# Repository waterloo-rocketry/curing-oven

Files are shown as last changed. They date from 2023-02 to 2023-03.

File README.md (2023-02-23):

# curing-oven

repository to store all the code and data for the curing oven project

call/text Calvin DeKoter at 650-399-6428 to ask about the project / or give UI tips

TODO 

Things to Fix

	Firmware

		List of issues detailed in powerpoint and also in the code itself
		General performance / best practice things could also be better

	Electrical
		
		There are some layout issues - currently the pressure sensor has been flywired
		A few other flywires and cut traces on the indicator LEDs

		Analog inputs and outputs are untested

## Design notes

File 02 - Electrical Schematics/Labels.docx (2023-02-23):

240 V X 240 V X | 240 V Y 240 V Y | DSW Y DSW Y | DSW X DSW X | AC DC X AC DC X | AC DC Y AC DC Y | OAL X OAL X
OAL Y OAL Y | HTR1 X HTR1 X | HTR1 Y HTR1 Y | BLW1 X BLW1 X | BLW1 Y BLW1 Y | IRO X IRO X | IRO Y IRO Y
SSR1 X SSR1 X | DWYER X DWYER X | F HTR1 X F HTR1 X | F HTR1 Y F HTR1 Y | F BLW1 X F BLW1 X | F BLW1 Y F BLW1 Y | AUX L AUX L
AUX G AUX G | AUX N AUX N | AUX L R AUX L R | IL ESTP IL ESTP | IL TFUSE IL TFUSE | IL DSW IL DSW | 240 V F X 240 V F X
240 V F Y 240 V F Y | AUX L F AUX L F | BUTTONS BUTTONS | DISPLAY DISPLAY | LED1 LED1 | LED2 LED2 | LED3 LED3
240 V X 240 V X | 240 V Y 240 V Y | DSW Y DSW Y | DSW X DSW X | AC DC X AC DC X | AC DC Y AC DC Y | OAL X OAL X
OAL Y OAL Y | HTR1 X HTR1 X | HTR1 Y HTR1 Y | BLW1 X BLW1 X | BLW1 Y BLW1 Y | IRO X IRO X | IRO Y IRO Y
SSR1 X SSR1 X | DWYER X DWYER X | F HTR1 X F HTR1 X | F HTR1 Y F HTR1 Y | F BLW1 X F BLW1 X | F BLW1 Y F BLW1 Y | AUX L AUX L
AUX G AUX G | AUX N AUX N | AUX L R AUX L R | IL ESTP IL ESTP | IL TFUSE IL TFUSE | IL DSW IL DSW | 240 V F X 240 V F X
240 V F Y 240 V F Y | AUX L F AUX L F | BUTTONS BUTTONS | DISPLAY DISPLAY | LED1 LED1 | LED2 LED2 | LED3 LED3

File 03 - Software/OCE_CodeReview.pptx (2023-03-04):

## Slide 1

Oven Code Review
- Code Purpose
  - Accept User Input from buttons
  - Control OCE Outputs, Measure Inputs
  - Manage Errors and Unexpected Inputs

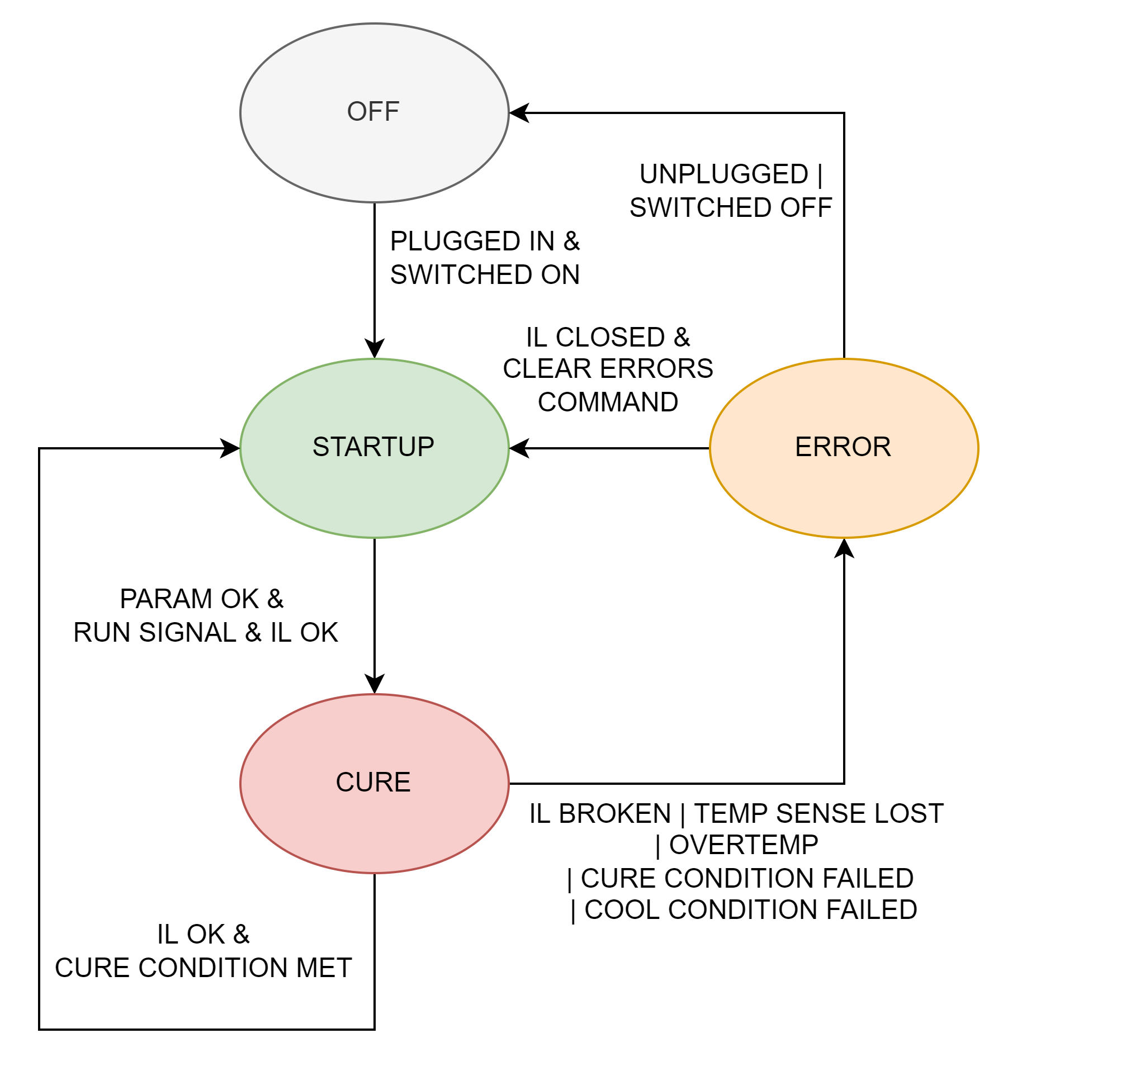
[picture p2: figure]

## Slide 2

List of Issues

Issue Name | Description | Proposed Fix
DataSave Overwrite | DataSave overwrites previous file | Check if the file exists, increment filename if so, display filename on screen
Fix padding | Numbers move around / poorly padded | Add a helper function to display the correct number and in the right position
Control off Screen | C leaves screen on Cure state | Pad number correctly
Therm. 7-9 deselect not working | Interesting | Weird wrapping stuff

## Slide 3

List of Todos

Issue Name | Description | Proposed Fix
Thermistor Screen | Add thermistor screen with all values | Fix scrolling between screens during cure
Real time clock | Add the RTC to the file header | Use the Teensy RTC synced to the PC
Log process T | Log the average temperature | Add a column to the data file
Protect AUX | Protect AUX from on/off cycling | Add a deadtime to the AUX output to avoid repeated starts
EEPROM settings | Oven can save current settings | If the user wishes (control tab), save setup to EEPROM
Ambient Setpoint | Ambient may not match actual | Collect a few seconds of data to set the ambient
OVT / Setpoint Ctrl | Balance setpoint control with OVT | Improve handoff between to targets to prevent oscillation
Menu Issues | Back button goes all the way to the main menu | Fix timing issues (see diagram on startup slide) to properly catch button presses
Thermistor Select | Cursor starts on description text | Adjust offsets so it works better
Cure Menu Display | Add more resolution to time displays | Swap units / padding when t < 1 h, t:tt > 1 h

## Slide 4

Safety Cases to Test

Case | Description | Expected Behaviour | Pass/Fail
Duct Disconnected | Duct is disconnected | No pitot tube, pressure switch wired NC | Fail
Oven Lid Open | Oven partially open | No ability to check without more IL routing | N/A, OoS
High Delta T | Thermistors not consistent | Check disabled to promote oven reliability, no response | Fail
Vacuum Leak | Leak, AUX on for full cure | Allow AUX to run for full cure
PCB Failure | Damage to PCB | Thermal fuse breaks IL after heater runaway | To Check

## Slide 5

Big Questions

Logging file format - .csv
Might be neat to have something with headers

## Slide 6

State 1: Startup

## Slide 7

State 2: Cure

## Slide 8

PID Control

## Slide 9

State 3: Error

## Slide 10

Function Description: driveHTR1()

Function operates on volatile variables to turn the heater output (that switches the SSR) on or off to generate a PWM signal at 60 Hz, duty cycle 0-100%

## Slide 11

Oven Digital Twin

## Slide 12

void setup()

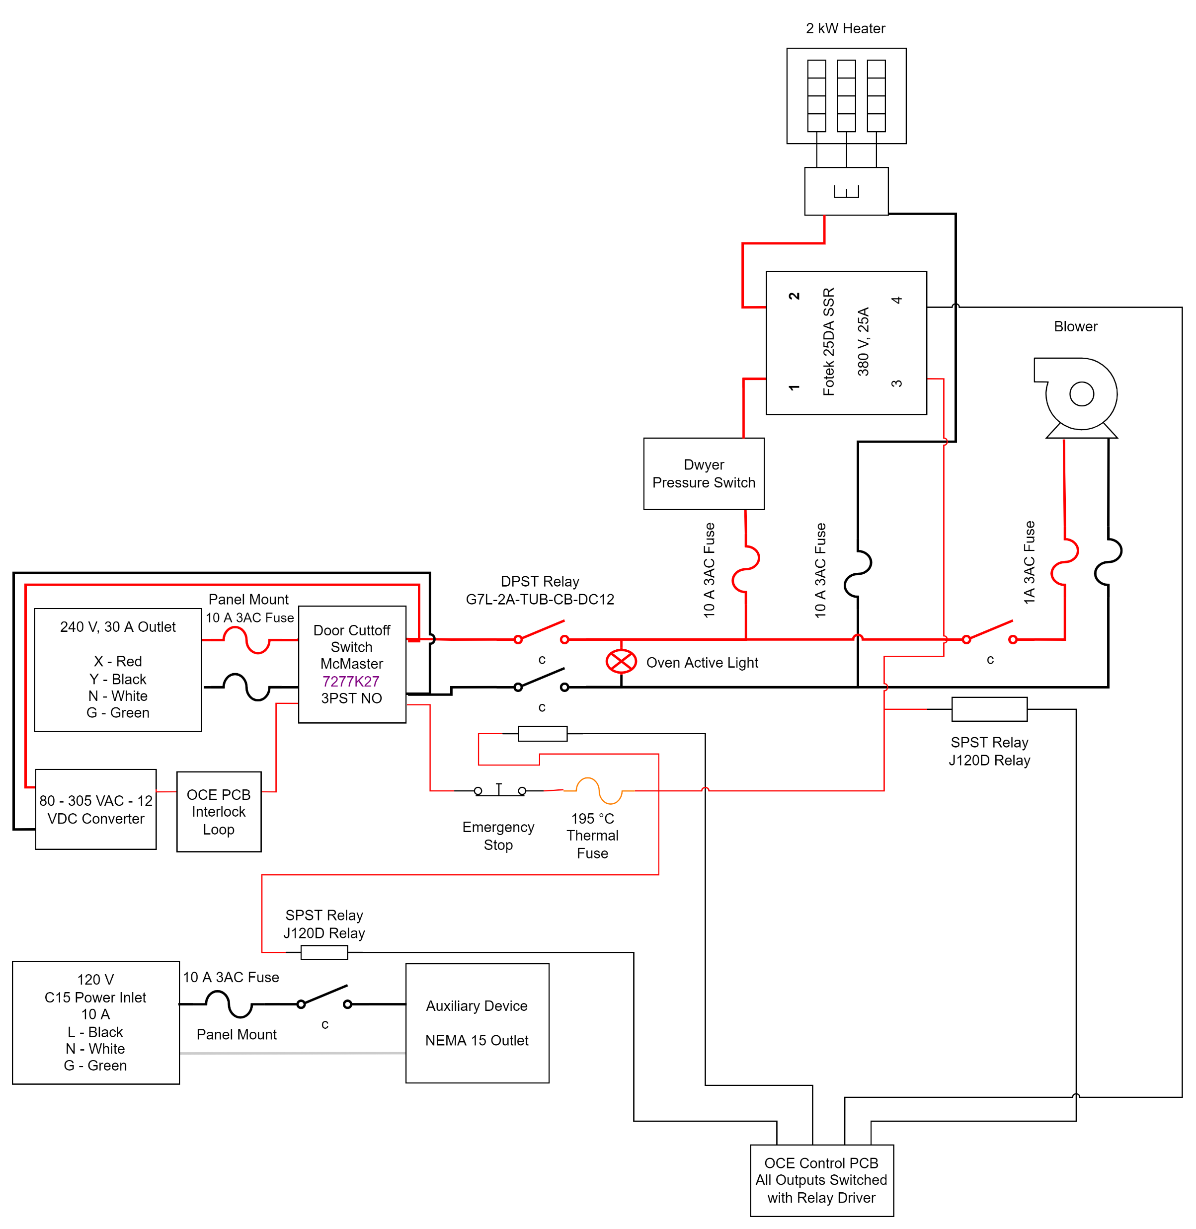
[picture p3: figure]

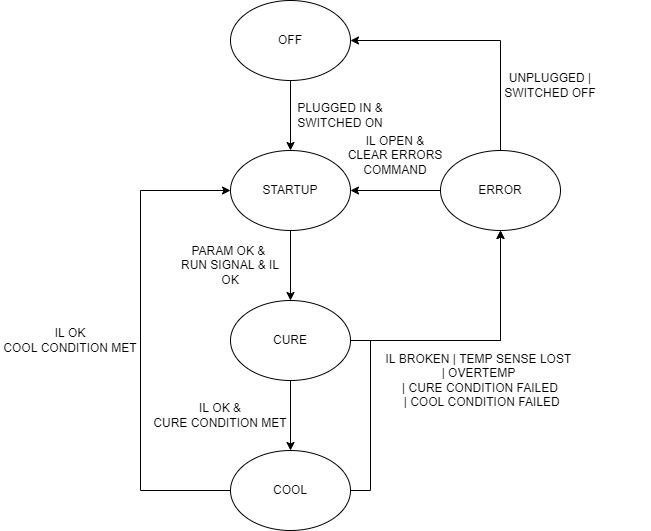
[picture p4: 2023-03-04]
03 - Software/OCE_StateMachine_V2.png

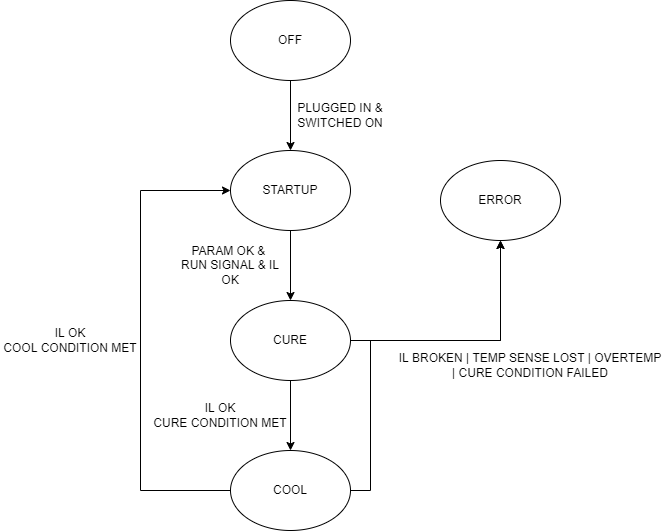
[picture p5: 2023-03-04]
03 - Software/OCE_StateMachine_V1.png

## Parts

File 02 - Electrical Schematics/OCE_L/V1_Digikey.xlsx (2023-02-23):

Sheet: OCE_L (2)
Id | Designator | Package | Quantity | Designation | Supplier and ref | Column1 | _1 | post-PCB
1 | U1 | SOT-223-3_TabPin2 | 1 | AZ1117-3.3 |  |  |  | done
2 | J6 | PinSocket_1x03_P2.54mm_Vertical | 1 | Conn_01x03_Female
3 | U5 | SOT-223-3_TabPin2 | 1 | AZ1117-5.0
4 | U4 | SOIC-16W_7.5x10.3mm_P1.27mm | 1 | MLX90809 |  |  |  | done
5 | J4 | PinSocket_2x12_P2.54mm_Vertical | 1 | Conn_01x24_Female |  |  |  | done
6 | J3 | PinHeader_2x04_P2.54mm_Vertical_Lin | 1 | Conn_02x04_Counter_Clockwise |  |  |  | done
7 | K2,K1 | J120D | 2 | J120D |  |  |  | done
8 | J9 | J1B1211CCD | 1 | J1B1211CCD |  |  |  | done
9 | IC1 | TEENSY41 | 1 | TEENSY_4.1 |  |  |  | done
10 | C3,C4,C5,C6,C16,C22 | C_0805_2012Metric | 6 | 0.1uF
11 | C7,C25,C26 | C_0805_2012Metric | 3 | 100 nF
12 | C9,C11,C12,C13,C14,C15,C17,C18,C19,C20,C21 | C_0805_2012Metric | 11 | 10uF
13 | C10 | C_0805_2012Metric | 1 | 47 nF
14 | J1 | PinSocket_2x03_P2.54mm_Vertical | 1 | Conn_02x03_Counter_Clockwise
15 | J2 | BarrelJack_Horizontal | 1 | Barrel_Jack
16 | R22,R41 | R_0805_2012Metric | 2 | 3.3k
17 | R27,R40 | R_0805_2012Metric | 2 | 4.7k
18 | U2 | SOIC-16_4.55x10.3mm_P1.27mm | 1 | ULQ2004A
19 | U3 | DIP-14_W10.16mm | 1 | LM324
20 | RV1,RV2 | 64WR50KLF | 2 | R_POT
21 | C1,C2 | C_0805_2012Metric | 2 | 10 uF
22 | C23,C24 | C_0805_2012Metric | 2 | 22 uF
23 | R1,R2,R4,R5,R8,R9,R11,R12,R13,R15,R16,R17,R18,R19,R20,R21,R23,R24,R25,R26,R29,R30,R31,R32,R33,R34,R35,R36,R37,R38,R39 | R_0603_1608Metric | 31 | 10k
24 | R7,R10 | R_0603_1608Metric | 2 | 40k
25 | R28 | R_0603_1608Metric | 1 | 10K
26 | J5 | PinSocket_2x10_P2.54mm_Vertical | 1 | Conn_02x10_Odd_Even
27 | J10 | PinSocket_2x03_P2.54mm_Vertical | 1 | Conn_02x03_Odd_Even
28 | U6 | TJA1044 | 1 | TJA1044
29 | R3,R6 | R_0603_1608Metric | 2 | 60
30 | U7 | SOIC-16W_7.5x10.3mm_P1.27mm | 1 | MLX90821

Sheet: OCE_L_V1.2
Id | Designator | Package | Quantity | Designation | Supplier and ref | Column1 | _1
1 | J2 | Kycon-KLDX-0202-A-MFG | 1 | Barrel_Jack
2 | IC1 | MODULE_DEV-16771 | 1 | DEV-16771
3 | U8 | AD8494ARMZ | 1 | AD8494ARMZ
4 | R12,R2,R5,R8,R9,R11,R13,R15,R16,R17,R18,R19,R20,R21,R23,R24,R25,R26,R29-R39,R42,R43,R46,R47,R1,R4,R49 | R_0603_1608Metric | 36 | 10k
5 | U1 | SOT-223-3_TabPin2 | 1 | AZ1117-3.3
6 | J6 | PinSocket_1x03_P2.54mm_Vertical | 1 | Conn_01x03_Female
7 | U5 | SOT-223-3_TabPin2 | 1 | AZ1117-5.0
8 | J4 | PinSocket_2x12_P2.54mm_Vertical | 1 | Conn_01x24_Female
9 | J3 | PinHeader_2x04_P2.54mm_Vertical_Lin | 1 | Conn_02x04_Counter_Clockwise
10 | J9 | J1B1211CCD | 1 | J1B1211CCD
11 | C3,C5,C6,C16,C22,C4 | C_0805_2012Metric | 6 | 0.1uF
12 | C7,C10 | C_0805_2012Metric | 2 | 47 nF
13 | C9,C11,C12,C13,C14,C15,C17,C18,C19,C20,C21 | C_0805_2012Metric | 11 | 10uF
14 | R22,R41 | R_0805_2012Metric | 2 | 3.3k
15 | R27,R40 | R_0805_2012Metric | 2 | 4.7k
16 | U2 | SOIC-16_4.55x10.3mm_P1.27mm | 1 | ULQ2004A
17 | U3 | DIP-14_W10.16mm | 1 | LM324
18 | RV1,RV2 | 64WR50KLF | 2 | R_POT
19 | C1,C2 | C_0805_2012Metric | 2 | 10 uF
20 | C23,C24 | C_0805_2012Metric | 2 | 22 uF
21 | R7,R10 | R_0603_1608Metric | 2 | 40k
22 | R28 | R_0603_1608Metric | 1 | 10K
23 | J5 | PinSocket_2x10_P2.54mm_Vertical | 1 | Conn_02x10_Odd_Even
24 | J10 | PinSocket_2x03_P2.54mm_Vertical | 1 | Conn_02x03_Odd_Even
25 | U6 | TJA1044 | 1 | TJA1044
26 | R3,R6 | R_0603_1608Metric | 2 | 60
27 | C25,C26 | C_0805_2012Metric | 2 | 100 nF
28 | U7 | SOIC-16W_7.5x10.3mm_P1.27mm | 1 | MLX90821
29 | C8,C28 | C_0805_2012Metric | 2 | 1 uF
30 | C27 | C_0805_2012Metric | 1 | 1 nF
31 | J11 | PinSocket_1x02_P2.54mm_Vertical | 1 | Conn_01x02_Female
32 | R14 | R_0805_2012Metric | 1 | 1M
33 | D1,D2 | MMSZ3V3T1G | 2 | Zener_3.3
34 | R44,R45 | R_0603_1608Metric | 2 | 1k
35 | B1 | BK-912-TR | 1 | BK-912-TR
36 | C29 | C_0805_2012Metric | 1 | 0.1 uF
37 | J1 | oce | 1 | Screw_Terminal_01x02
38 | J7 | PinHeader_1x03_P2.54mm_Vertical | 1 | Conn_01x03_Male
39 | R50 | R_0603_1608Metric | 1 | 2.5k
40 | K1,K2 | J120D | 2 | J120D
41 | U4 | MLX90809 | 1 | MLX90809

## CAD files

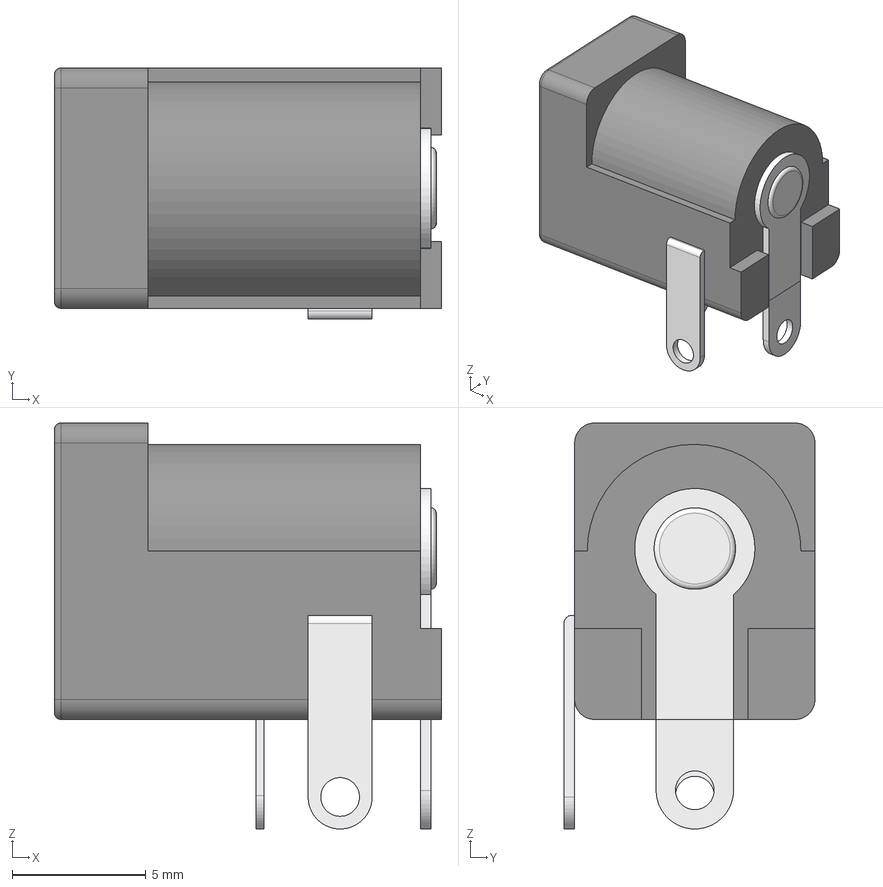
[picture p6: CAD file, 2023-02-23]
02 - Electrical Schematics/Components/Conn_Kycon_KLDX-0202-A/eec.models/Kycon_-_KLDX-0202-A.step
14.5 x 9.40 x 15.2 mm

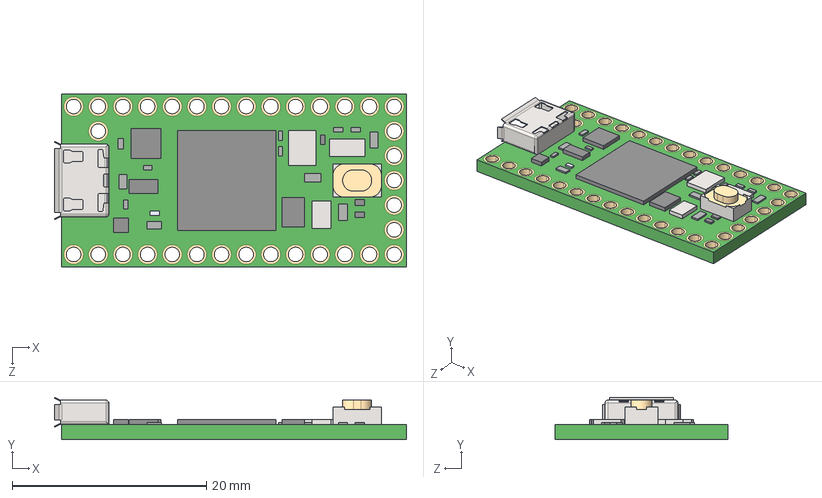
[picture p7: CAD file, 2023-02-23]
02 - Electrical Schematics/Components/LIB_TEENSY_4.0/TEENSY_4.0/3D/TEENSY_4.0.stp
36.3 x 4.36 x 17.8 mm

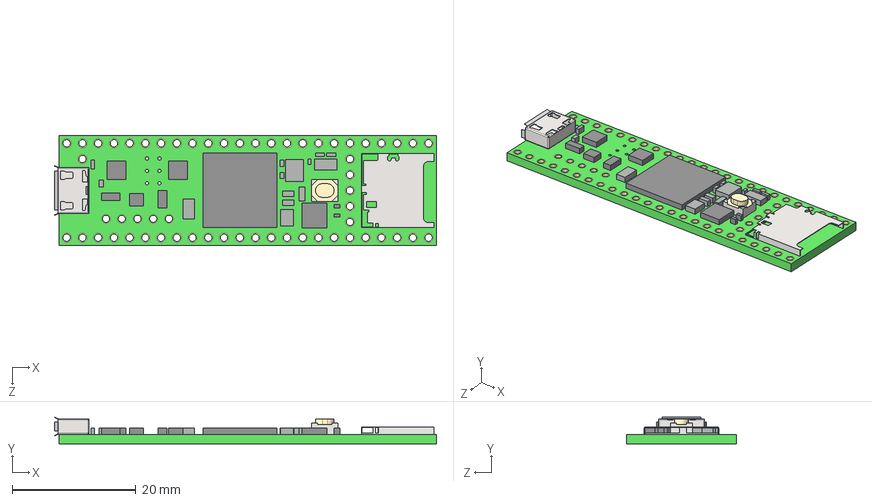
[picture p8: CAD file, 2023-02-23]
02 - Electrical Schematics/Components/LIB_TEENSY_4.1/TEENSY_4.1/3D/TEENSY_4.1.stp
61.7 x 4.35 x 17.8 mm

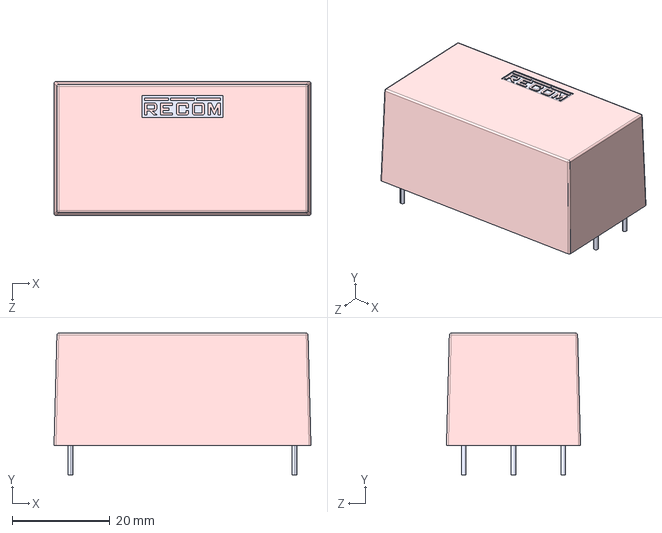
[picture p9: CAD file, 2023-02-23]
02 - Electrical Schematics/Components/RAC10-12SK_277/RAC10-12SK_277.step
52.5 x 29.0 x 27.4 mm

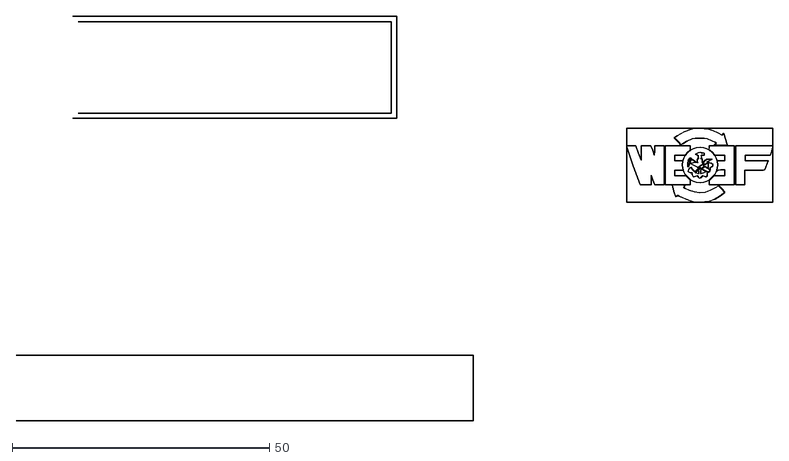
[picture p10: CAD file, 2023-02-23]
02 - Electrical Schematics/OCE_L/OCE_L-Dwgs_User.dxf
147.2 x 78.6

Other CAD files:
02 - Electrical Schematics/Components/LIB_TEENSY_4.0/TEENSY_4.0/Allegro/teensy40.psm
02 - Electrical Schematics/Components/LIB_TEENSY_4.0/TEENSY_4.0/DEHDL/teensy_4.0/chips/chips.prt
02 - Electrical Schematics/Components/LIB_TEENSY_4.1/TEENSY_4.1/Allegro/teensy41.psm
02 - Electrical Schematics/Components/LIB_TEENSY_4.1/TEENSY_4.1/DEHDL/teensy_4.1/chips/chips.prt

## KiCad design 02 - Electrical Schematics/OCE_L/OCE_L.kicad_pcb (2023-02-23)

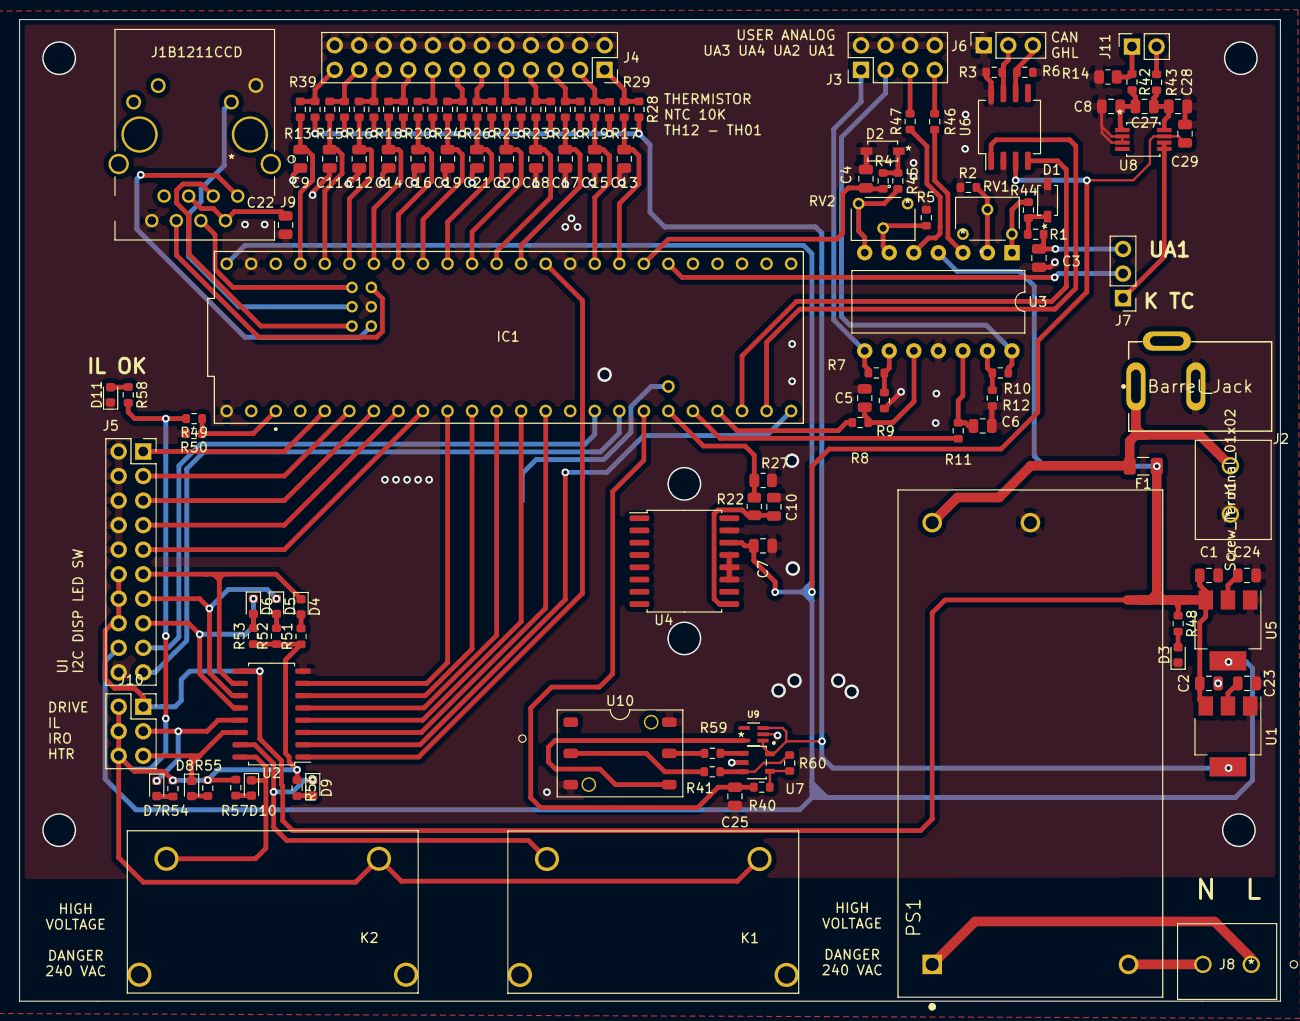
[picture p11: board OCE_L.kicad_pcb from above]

Board: 2 copper layers, 130.5 x 101.6 mm, 128 parts (1 on the bottom side), 109 nets.

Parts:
B1: BK-912-TR
C1, C2: 10 uF; C_0805_2012Metric
C3, C4, C5, C6, C16, C22: 0.1uF; C_0805_2012Metric
C7, C10: 47 nF; C_0805_2012Metric
C8, C25, C28: 1 uF; C_0805_2012Metric
C9, C11, C12, C13, C14, C15, C17, C18, C19, C20, C21: 10uF; C_0805_2012Metric
C23, C24: 22 uF; C_0805_2012Metric
C27: 1 nF; C_0805_2012Metric
C29: 0.1 uF; C_0805_2012Metric
D1, D2: Zener_3.3; MMSZ3V3T1G
D3, D4, D5, D6, D7, D8, D9, D10, D11: LED; LED_0603_1608Metric
F1: 1 A 1206 Fuse; Fuse_1206_3216Metric
IC1: DEV-16771; MODULE_DEV-16771
J1, J8: Screw_Terminal_01x02; oce
J2: Barrel_Jack; Kycon-KLDX-0202-A-MFG
J3: Conn_02x04_Counter_Clockwise; PinHeader_2x04_P2.54mm_Vertical_Lin
J4: Conn_01x24_Female; PinSocket_2x12_P2.54mm_Vertical
J5: Conn_02x10_Odd_Even; PinSocket_2x10_P2.54mm_Vertical
J6: Conn_01x03_Female; PinSocket_1x03_P2.54mm_Vertical
J7: Conn_01x03_Male; PinHeader_1x03_P2.54mm_Vertical
J9: J1B1211CCD
J10: Conn_02x03_Odd_Even; PinSocket_2x03_P2.54mm_Vertical
J11: Conn_01x02_Female; PinSocket_1x02_P2.54mm_Vertical
K1, K2: J120D
PS1: RAC10-12SK_277; CONV_RAC10-12SK_277
R1, R2, R4, R5, R8, R9, R11, R12, R13, R15, R16, R17, R18, R19, R20, R21, R23, R24, R25, R26, R40, R42, R43, R46, R47, R49: 10k; R_0603_1608Metric
R3, R6: 60; R_0603_1608Metric
R7, R10: 40k; R_0603_1608Metric
R14: 1M; R_0805_2012Metric
R22: 3.3k; R_0805_2012Metric
R27: 4.7k; R_0805_2012Metric
R28, R29, R30, R31, R32, R33, R34, R35, R36, R37, R38, R39, R41, R44, R45, R48, R51, R52, R53, R54, R55, R56, R57, R58, R59: 1k; R_0603_1608Metric
R50: 2.5k; R_0603_1608Metric
R60: 100k; R_0603_1608Metric
RV1, RV2: R_POT; 64WR50KLF
U1: AZ1117-3.3; SOT-223-3_TabPin2
U2: ULQ2004A; SOIC-16_4.55x10.3mm_P1.27mm
U3: LM324; DIP-14_W10.16mm
U4: MLX90809
U5: AZ1117-5.0; SOT-223-3_TabPin2
U6: TJA1044
U7: AS321KTR-G1
U8: AD8494ARMZ
U9: MIC5366-1.8YC5-TR; SOT65P210X110-5N
U10: BLC-L01D-U2

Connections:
1V8: U9.5, U10.3
3V3: C23.1, R28.2, R29.2, R30.2, R31.2, R32.2, R33.2, R34.2, R35.2, R36.2, R37.2, R38.2, R39.2, U1.2, U7.5, U9.1, U9.3
5V: C7.1, C24.2, C29.1, J5.18, U4.3, U5.2, U6.3, U8.7
12V: F1.2, J1.2, J2.1, PS1.5
12V_F: C1.1, C2.2, F1.1, J5.12, J5.14, J5.16, J10.1, R48.1, U1.3, U2.9, U3.4, U5.3
12V_IL: J10.2, J10.4, J10.6, K1.1, K2.1, R49.2, R51.1, R52.1, R53.1, R54.1, R55.1, R56.1, R57.1, R58.2
AUX1: D9.1, K1.2, U2.15
AUX1_EN: IC1.32, U2.2
BLC_VOUTM: R41.1, R60.1, U7.3
BLC_VOUTP: R59.2, U7.1
BLW1: D10.1, K2.2, U2.16
BLW1_EN: IC1.13, U2.1
CAN_RX: IC1.30, U6.4
CAN_TX: IC1.31, U6.1
ETH_LED: IC1.LED, J9.10
ETH_RX+: IC1.R+, J9.4
ETH_RX-: IC1.R-, J9.6
ETH_TX+: IC1.T+, J9.1
ETH_TX-: IC1.T-, J9.3
GND: B1.3, C1.2, C2.1, C3.2, C4.2, C5.2, C6.2, C7.2, C8.1, C9.2, C10.2, C11.2, C12.2, C13.2, C14.2, C15.2, C16.2, C17.2, C18.2, C19.2, C20.2, C21.2, C22.1, C23.2, C24.1, C25.1, C28.1, C29.2, D1.2, D2.2, D3.1, D11.1, IC1.GND1, IC1.GND2, IC1.GND3, IC1.GND5, J1.1, J2.2, J3.5, J3.6, J3.7, J3.8, J4.2, J4.4, J4.6, J4.8, J4.10, J4.12, J4.14, J4.16, J4.18, J4.20, J4.22, J4.24, J5.2, J5.4, J5.6, J5.8, J5.10, J5.20, J6.1, J9.8, J9.9, PS1.4, R2.2, R3.2, R5.2, R6.2, R9.1, R12.1, R14.2, R27.1, R50.2, U1.1, U2.8, U3.11, U4.2, U4.4, U4.5, U4.6, U5.1, U6.2, U6.8, U7.2, U8.2, U8.3, U9.2, U10.1, U10.6
HTR1: D8.1, J10.5, U2.14
HTR1_EN: IC1.12, U2.3
IRO1: D7.1, J10.3, U2.13
IRO1_EN: IC1.11, U2.4
LED1: IC1.8, U2.7
LED1_DR: D4.1, J5.11, U2.10
LED2: IC1.9, U2.6
LED2_DR: D5.1, J5.13, U2.11
LED3: IC1.10, U2.5
LED3_DR: D6.1, J5.15, U2.12
unnamed: C3.1, J7.3, R1.2
unnamed: C5.1, R8.1, U3.10
unnamed: C6.1, R11.1, U3.12
unnamed: C10.1, R22.2, U4.8
unnamed: C22.2, J9.2, J9.5
unnamed: C27.1, C28.2, R43.1, U8.8
unnamed: C8.2, C27.2, R42.1, U8.1
unnamed: D1.1, R1.1, R44.2
unnamed: D2.1, R4.1, R45.2
unnamed: D3.2, R48.2
unnamed: D4.2, R51.2
unnamed: D5.2, R52.2
unnamed: D6.2, R53.2
unnamed: D7.2, R54.2
unnamed: D8.2, R55.2
unnamed: D9.2, R56.2
unnamed: D10.2, R57.2
unnamed: D11.2, R58.1
unnamed: J3.1, R7.2, U3.8
unnamed: J3.2, R10.2, U3.14
unnamed: J3.3, R47.2
unnamed: J3.4, R46.2
unnamed: J4.1, R17.1, R28.1
unnamed: J4.3, R19.1, R29.1
unnamed: J4.5, R21.1, R30.1
unnamed: J4.7, R23.1, R31.1
unnamed: J4.9, R25.1, R32.1
unnamed: J4.11, R26.1, R33.1
unnamed: J4.13, R24.1, R34.1
unnamed: J4.15, R20.1, R35.1
unnamed: J4.17, R18.1, R36.1
unnamed: J4.19, R16.1, R37.1
unnamed: J4.21, R15.1, R38.1
unnamed: J4.23, R13.1, R39.1
unnamed: J6.2, R3.1, U6.7
unnamed: J6.3, R6.1, U6.6
unnamed: J7.1, U8.5, U8.6
unnamed: J8.1, PS1.1
unnamed: J8.2, PS1.2
unnamed: J11.1, R14.1, R42.2
unnamed: J11.2, R43.2
unnamed: R2.1, RV1.2, U3.2
unnamed: R5.1, RV2.2, U3.6
unnamed: R7.1, R9.2, U3.9
unnamed: R10.1, R12.2, U3.13
unnamed: R40.1, R60.2, U7.4
unnamed: R41.2, U10.5
unnamed: R44.1, RV1.3, U3.1
unnamed: R45.1, RV2.3, U3.7
unnamed: R46.1, U3.3
unnamed: R47.1, U3.5
unnamed: R59.1, U10.2
PIT1: C25.2, IC1.26, R40.2
SCL2: IC1.24, J5.17
SDA2: IC1.25, J5.19
SEN_IL: IC1.1, R49.1, R50.1
SW1: IC1.3, J5.1
SW2: IC1.4, J5.3
SW3: IC1.5, J5.5
SW4: IC1.6, J5.7
SW5: IC1.7, J5.9
TH01_IN: C13.1, IC1.40, R17.2
TH02_IN: C15.1, IC1.41, R19.2
TH03_IN: C17.1, IC1.14, R21.2
TH04_IN: C18.1, IC1.15, R23.2
TH05_IN: C20.1, IC1.16, R25.2
TH06_IN: C21.1, IC1.17, R26.2
TH07_IN: C19.1, IC1.18, R24.2
TH08_IN: C16.1, IC1.19, R20.2
TH09_IN: C14.1, IC1.20, R18.2
TH10_IN: C12.1, IC1.21, R16.2
TH11_IN: C11.1, IC1.22, R15.2
TH12_IN: C9.1, IC1.23, R13.2
UA1: IC1.38, J7.2
UA2: C4.1, IC1.39, R4.2
UA3_OUT: IC1.29, R8.2
UA4_OUT: IC1.28, R11.2
VBAT: B1.1, B1.2, IC1.VBAT
VS1: IC1.27, R22.1, R27.2

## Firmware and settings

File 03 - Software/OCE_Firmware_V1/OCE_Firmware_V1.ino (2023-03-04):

// OCE Firmware V1
// Calvin DeKoter
// Power Ranchers, Group 41
// Code is designed to run on the Teensy 4.1, with a custom PCB and all the necessary hardware

// Stuff to add

// Calibration routine for the user analog inputs with variable gain - use the user analog outputs

// Used Libraries

#include <LiquidCrystal_I2C.h> // need to switch the header in the library to use Wire2
#include <TimeLib.h>
#include <Bounce.h> // Library to debounce switch inputs
#include <IntervalTimer.h> // Library to create timer interrupt objects
#include <Ethernet.h> // Library to post data to the internet
// Teensy CAN

// Function Prototypes

void pushOUT() ;
void pushUPW() ;
void pushDWN() ;
void pushSLT() ;
void pushRUN() ;

void ILBRK() ;

void driveHTR1() ;

// Pin Assignments

const int AIN_c = 16 ; 
// number of analog input pins
int AIN[] = {40,41,14,15,16,17,18,19,20,21,22,23,38,39,27,26} ;
// physical pin numbers of each of the analog input pins
bool AIN_u[] = {true,false,false,false,false,false,false,false,false,false,false,false,false,false,false,false,} ;
// If the pin is in use, mark it to be read during the cure and cool states
char *AIN_n[] = {"TH01","TH02","TH03","TH04","TH05","TH06","TH07","TH08","TH09","TH10","TH11","TH12","UA1","UA2","VS1","PIT1"} ;
// Names of all the analog input pins

int AOUT[] =  {29,28} ;
char *AOUT_n[] = {"UA3","UA4"} ;

int SW_c = 5 ;
int SW[] = {3,4,5,6,7} ;
char *SW_n[] = {"OUT","UPW","DWN","SLT","RUN"} ;

IntervalTimer control_HTR1_Timer ;

int DRV_c = 7 ;
int DRV[] = {11,13,12,32,8,9,10}; // Input Relay, Blower, Heater, Auxiliary, and LED Enable Pins 
char *DRV_n[] = {"IRO1","BLW1","HTR1","AUX1","LED1","LED2","LED3"};

int state = 1 ; // Start in the startup state
char *state_n[] = {"OFF","STARTUP","CURE","COOL","ERROR"} ;

int SEN_IL = 1 ;
int UA3 = 29 ;
int UA4 = 28 ;

int error_c = 6 ;
char *error[] = {"None      ","          ","          ","          ","          ","          "} ; // Array to hold the error strings
int error_count = 0 ;

char clearline = "                                        " ;

bool stateChange = false ;
bool ILOK = false ;     // Boolean to indicate the state of the interlock loop
bool paramOK = false ;  // Boolean to indicate the validity of the parameters (all positive, nonzero, temp less than Temp_Max_Part)
bool CURE = false ;
bool COOL = false ;
bool ERR = false ;

volatile bool OUT = false ;
volatile bool UPW = false ;
volatile bool DWN = false ;
volatile bool SLT = false ;
volatile bool RUN = false ;

// Oven Properties

int Temp_Max = 200 ; // Degrees C, immediate shutdown if exceeded
int Temp_Max_Control = 180 ; // Maximum temperature that the oven will deliberately heat to
int Temp_Max_Part = 130 ; // Maximum part temperature
int Temp_Min = 0 ; // Indicates an open thermistor circuit, does not necessarily cause a shutdown unless all circuits are open

int Time_heat = 1*3600*1000 ; // Heating ramp time in milliseconds
int Time_hold = 1*3600*1000 ; // Hold time in milliseconds
int Time_cool = 1*3600*1000 ; // Cool time in milliseconds

int Temp_set = 80 ; // Degrees C
float Temp_avg = 0 ; // Average Temperature

float UA1_gain = 1 ; // Gain for the two user inputs
float UA2_gain = 2 ; 

LiquidCrystal_I2C lcd(0x27,20,4);  // set the LCD address to 0x27 for a 16 chars and 2 line display

// Controller Properties

float Kp = 1 ; // Will be challenging to find a good set of gains for every circumstance - will consider gain scheduling or a self-calibration sequence
float Kd = 0.1 ;
float Ki = 0.1 ;

volatile int cycle = 1 ;
volatile int control_HTR1_count = 0 ;
volatile float control_HTR1 = 0 ; // Range of time HTR1 is enabled, over 1 second - 0 - 59 out of 60 electrical cycles

// Data Structures
const int data_width = 1 + AIN_c ;

float data[data_width] ;  

void setup() {

  for(int i=0;i<AIN_c;1) // Assign the analog input pins to the analog mode
  {
    pinMode(AIN[i],INPUT) ;
  }

  for(int j=0;j<SW_c;1) // Assign the switch inputs to input pullup mode
  {
    pinMode(SW[j],INPUT_PULLUP) ;
  }
  
  attachInterrupt(digitalPinToInterrupt(SW[1]), pushOUT, FALLING) ;
  attachInterrupt(digitalPinToInterrupt(SW[2]), pushUPW, FALLING) ;
  attachInterrupt(digitalPinToInterrupt(SW[3]), pushDWN, FALLING) ;
  attachInterrupt(digitalPinToInterrupt(SW[4]), pushSLT, FALLING) ;
  attachInterrupt(digitalPinToInterrupt(SW[5]), pushRUN, FALLING) ;

  for(int k=0;k<DRV_c;1) // Assign the drive output to output mode
  {
    pinMode(DRV[k],OUTPUT) ;
  }

  pinMode(SEN_IL,INPUT_PULLDOWN) ;
  attachInterrupt(digitalPinToInterrupt(SEN_IL), ILBRK, FALLING) ;
  
  pinMode(UA3,OUTPUT) ;
  pinMode(UA4,OUTPUT) ;  
}

void loop() {
  
  if(state = 1 && !stateChange) // Enter the STARTUP State
  {
    lcd.setCursor(30,0) ; // Write the state name to the top right corner of the LCD
    lcd.print(state_n[state]) ; 

    if(!ILOK)
    {
      lcd.setCursor(3,1) ;
      lcd.print("INTERLOCK LOOP OPEN") ;
      state = 1 ;
    }

      int curs = 0 ; // High level menu cursor
      
    while(ILOK && !RUN && !paramOK)
    {
      // Menu for setting all parameters
      lcd.setCursor(2,0) ;
      lcd.print("MAIN MENU   ") ;
      lcd.println(" CURE") ;
      lcd.setCursor(15,1) ;
      lcd.println(" SENSE") ;
      lcd.setCursor(15,2) ;
      lcd.println(" DATA") ;
      lcd.setCursor(15,3) ;
      lcd.println(" CTRL") ;

      lcd.setCursor(14,curs) ;
      lcd.print(">") ;

      int curs_cxt = 0 ; // Context Menu Cursor

      if(UPW)
      {
        curs += 1 ;
        delay(50) ;
        UPW = false ;
      }
      if(DWN)
      {
        curs -= 1 ;
        delay(50) ;
        DWN = false ;
      }
      
      delay(500) ;
      lcd.clear() ;
      
      while(curs == 0 && !OUT && SLT)
      {
        delay(50) ; 
        SLT = false ;
        
        // Cure Menu
        lcd.setCursor(2,0) ;
        lcd.print("Temp. Target: ") ;
        lcd.print(Temp_set) ;
        lcd.setCursor(2,1) ;
        lcd.print("Time Heat: ") ;
        lcd.print(Time_heat/(60*1000)) ;
        lcd.print("[min]") ;
        lcd.setCursor(2,2) ;
        lcd.print("Time Hold: ") ;
        lcd.print(Time_hold/(3600*1000)) ;
        lcd.print("[h]") ;
        lcd.setCursor(2,0) ;
        lcd.print("Time Cool: ") ;
        lcd.print(Time_cool/(60*1000)) ;
        lcd.print("[min]") ;

        lcd.setCursor(2,curs_cxt) ;
        
        if(UPW)
        {
          curs_cxt += 1 ;
          delay(50) ;
          UPW = false ;
        }
        if(DWN)
        {
          curs_cxt -= 1 ;
          delay(50) ;
          DWN = false ;
        }

        while(SLT && !OUT)
        {
          if(UPW) // If the up button has been pressed, increment the values
          {
            if(curs_cxt==0)
            {Temp_set += 2;}
            else if(curs_cxt==1)
            {Time_heat += 1000*60*5 ;}
            else if(curs_cxt == 2)
            {Time_hold += 1000*60*30 ;}
            else if(curs_cxt == 3)
            {Time_cool += 1000*60*5 ;}

            delay(50) ;
            UPW = false ;  
          }
          else if(DWN) // if the down button has been pressed, decrement the value
          {
            if(curs_cxt==0)
            {
              Temp_set -= 2;
              lcd.setCursor(16,curs_cxt) ;
              lcd.print(Temp_set) ;
            }
            else if(curs_cxt==1)
            {
              Time_heat -= 1000*60*5 ;
              lcd.setCursor(13,curs_cxt) ;
              lcd.print(Time_heat) ;
            }
            else if(curs_cxt == 2)
            {Time_hold -= 1000*60*30 ;}
            else if(curs_cxt == 3)
            {Time_cool -= 1000*60*5 ;}

            delay(50) ;
            DWN = false ;  
          }
          
           // Push the OUT button to exit the while loop
        }

        delay(50) ;
        OUT = false ;

        
        SLT = true ;
         
      }
      while(curs == 1 && SLT)
      {
        // Sense Menu  
        
        if(OUT)
        {
          SLT = false ;
        }
      }
      while(curs == 2 && SLT)
      {
        // Data Menu 
        
        if(OUT)
        {
          SLT = false ;
        } 
      }
      while(curs == 3 && SLT)
      {
        // Controller Menu 
        
        if(OUT)
        {
          SLT = false ;
        } 
      }
    }

    stateChange = true ;
    state = 2 ; // Proceed to the cure state
    
  }

  if(state = 2 && !stateChange) // Enter the CURE State
  {
    lcd.setCursor(30,0) ; // Write the state name to the top right corner of the LCD
    lcd.print(state_n[state]) ; 

    // Switch on the oven input relay
    digitalWrite(DRV[1],HIGH) ; // check whether the ULQ is active high or low
    digitalWrite(DRV[2],LOW) ;
    digitalWrite(DRV[3],LOW) ;
    digitalWrite(DRV[4],LOW) ;

    int Time_start = millis() ;
    int ts = 1000 ;
    int error_I = 0 ;
    float Temp_last = 0 ;
    int avg_c = 0 ;

    control_HTR1_Timer.begin(driveHTR1,16666) ;
  
    while(ILOK && CURE && !ERR)
    {
      
      // log the data - need a fuction

      data[0] = now() ; // Returns the time in seconds since 1970...

      // Calculate the rampline value

      
      Temp_last = Temp_avg ; // should be averaging the last and next temperatures over 10 seconds to avoid noise
      Temp_avg = 0 ;

      
      for(int d = 0;d<data_width;1)
      {
        if(AIN_u[d])
        {
          if(d+1<13) // Read in Thermistor Data
          {
            data[d+1] = analogRead(AIN[d]) ; // add temp conversion, polynomical NTC fit 
            if(data[d+1]<10)
            {
              error[error_count] = strcat(strcat("TH",char(d+1))," BRK") ; // Thermistor disconnected, move to oven ERROR state
              ERR = true ;
            }
            if(data[d+1]>200)
            {
              error[error_count] = strcat(strcat("TH",char(d+1))," OVT") ; // Overtemperature on thermistor, move to oven ERROR state
              ERR = true ;
            }
            Temp_avg += data[d+1] ;
            avg_c += 1;
          }
          
          if(12<d+1 && d+1<15) // Read in UA2 Data
          {
            data[d+1] = analogRead(AIN[d]) ; // add generic conversion to volts based on calibration
          } 
          

          if(d+1==15)
          {
            data[d+1] = analogRead(AIN[d]) ; // Read in the vacuum sensor pressure
          }

          if(d+1==16)
          {
            data[d+1] = analogRead(AIN[d]) ; // Read in the differential sensor pressure
          }
          
        }
      }
    
    Temp_avg = Temp_avg/avg_c ; // Need to decide on average vs. particular temp for control

    if(control_HTR1<59||control_HTR1<0)
    {
      error_I += (Temp_set-Temp_avg)*ts ;
    } 
    control_HTR1 = Kp*(Temp_set - Temp_avg)+Kd/ts*(Temp_last-Temp_avg)+Ki*error_I ;

    // at program start, we want to pin the heating controller 120 C target - 20 C
    // 50*KP > map to 0-59

     if(control_HTR1>59)
     {
      control_HTR1=59 ;
     }
     else if(control_HTR1<0)
     {
      control_HTR1=0 ;
     }

      // write the data to the webpage

      // client.println("

      delay(980) ; // Delay to avoid logging an obscene amount of data

      if(millis()>(Time_heat+Time_hold-Time_start))
      {
        CURE = false ;
      }
  }

    control_HTR1_Timer.end() ;
    stateChange = true ;

    if(!ERR && ILOK){state = 3 ;} // Enter the cool state
    else{state = 4;}

  }

  if(state == 3 && !stateChange) // Enter the COOL State
  {
    lcd.setCursor(30,0) ; // Write the state name to the top right corner of the LCD
    lcd.print(state_n[state]) ; 

    while(COOL && !ERR)
    {
    // log the data
    // write the data to the internet
    }

    stateChange = true ;
    
    if(!ERR){state = 1 ;} // Enter the startup state
    else{state = 4;}
  }

  if(state = 4 && !stateChange) // Enter the ERROR State
  // TODO for error state - make sure that all the prints happen correctly
  {
    for(int k = 0;k<DRV_c;1)
    {
      digitalWrite(DRV[k],LOW) ; // Shut down all the oven outputs
    }
    
    
    lcd.setCursor(30,0) ; // Write the state name to the top right corner of the LCD
    lcd.print(state_n[state]) ; 

    lcd.setCursor(3,0) ;
    lcd.print("Error State") ;
    lcd.setCursor(2,1) ;
    lcd.print(error[0]) ;
    lcd.setCursor(3,2) ;
    lcd.print("SLT and IL Open to reset") ;

    while(ERR && !SLT && ILOK)
    {

      for(int e=0;e<error_c;1)
      {
        if(error[e]!="          ")
        {
          lcd.setCursor(0,3) ;
          lcd.print(clearline) ;
          lcd.setCursor(1,3) ;
          lcd.print("Error: ") ;
          lcd.print(e) ;
          lcd.setCursor(10,3) ;
          lcd.print(error[e]) ;
          delay(1000) ;
        }
      }
    }

   stateChange = true ;
   state = 1 ; // Enter the startup state

    
  }

  delay(50) ;
  stateChange = false ;
  lcd.clear() ;

}

void pushOUT()
{OUT = true;}
void pushUWP()
{UPW = true;}
void pushDWN()
{DWN = true;}
void pushSLT()
{SLT = true;}
void pushRUN()
{RUN = true;}

void ILBRK() // Using an interrupt, watch for the SEN_IL pin falling from high to low
{
  ILOK = false ; // Indicate the IL state as broken
  error[error_count] = "IL BRK" ; // record the error
}

void driveHTR1()
{
  
  cycle += 1 ;

  if(control_HTR1<cycle*control_HTR1/60)
  {
    control_HTR1_count += 1 ;
    digitalWrite(DRV[3],HIGH) ; // Make sure to check the ULQ2004A behaviour
  }
  else
  {
    digitalWrite(DRV[3],LOW) ; // Make sure to check the ULQ2004A behaviour
  }
 
}

// https://learn.adafruit.com/sous-vide-powered-by-arduino-the-sous-viduino

// write all parameters to EEPROM

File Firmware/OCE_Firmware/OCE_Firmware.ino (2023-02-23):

// OCE Firmware V1
// Calvin DeKoter
// Power Ranchers, Group 41
// Code is designed to run on the Teensy 4.1, with a custom PCB and all the necessary hardware

// Stuff to add

// Things to fix

  // todo need to add second thermistor screen with all thermistor values during cure cycle

// LOA

  //  LOA     List of Acronyms
  //  OCE     Oven Control Elements
  //  IL      Interlock Loop
  //  AIN     Analog INput
  //  AOUT    Analog OUTput
  //  SW      SWitch
  //  DRV     DRiVe output
  //  SEN_IL  Interlock Loop SENse
  //  IL_OK   Interlock Loop OKay
  //  PGM_OK  ProGraM OKay
  //  ERR     ERRor
  //  AUX     AUXiliary output
  //  VACC    VACCuum | Yes, I know this is a spelling error
  //  PIT     PITot tube
  //  UA*     User Analog
  //  HTR1    HeaTeR output 1
  //  CTRL    ConTRoL
  //  OUT     OUT
  //  UPW     UPWards
  //  DWN     DoWN
  //  SLT     SeLecT
  //  RUN     RUN
  //  RST     ReSeT
  //  CURS    CURSor
  //  CURS_CXT  CURSor_ConteXT | 
  //  Temp_Targ Temperature Target | The temperature that the oven will heat to and maintain for the scheduled cure time 
  //  EEPROM  Electronically Erasable PROgrammable Memory | Non-volatile memory to store curing information between startups
  //  OoS     Out of Scope | Cool feature that wasn't implemented
  
  // Shirley TODO

    /* 
    Events
    Duct disconnected
    Oven is opened and not closed fully
    Not unsafe, but could result in part failure
    Max temp would be around 60C
    SHould have some sort of check to ensure oven is recirculating
    High thermal gradient in oven
    Should ensure highest temperature area of oven does not exceed 171
    Thermistor located in high/low spot
    Leak springs in bag
    Causes aux to be on for full duration of cure
    Thermistor falls off part
    Something happens to the PCB?
    Documentation
    ambient set in firmware *?  

*/


// Calibration routine for the user analog inputs with variable gain - use the user analog outputs
// Mode for datalogging/aux only - from control menu

// Used Libraries

#include <LiquidCrystal_Wire2_I2C.h> // need to switch the header in the library to use Wire2 - (library in ZIP file, move to general install location)
#include <TimeLib.h>
#include <IntervalTimer.h> // Library to create timer interrupt objects
#include <NativeEthernet.h> // Library to post data to the internet

#include <SD.h>
#include <SPI.h>

const int chipSelect = BUILTIN_SDCARD ;

// Enter a MAC address and IP address for your controller below.
// The IP address will be dependent on your local network:
byte mac[] = {
  0x04, 0xe9, 0xe5, 0x10, 0xbc, 0x26
};  

// Initialize the Ethernet server library
// with the IP address and port you want to use
// (port 80 is default for HTTP):
EthernetServer server(80);

// Teensy CAN

  //  The board has a CAN bus on it, but it was never implemented - that would be really cool if you could integrate the controller to manage temps on the car or rocket
    
// Function Prototypes

void pushOUT() ;
void pushUPW() ;
void pushDWN() ;
void pushSLT() ;
void pushRUN() ;

void ILBRK() ;

void driveHTR1() ;

float interpTherm(int dataRead) ;

// Pin Assignments
const int AIN_c = 16 ; // number of analog input pins
int AIN[] = {40,41,14,15,16,17,18,19,20,21,22,23,38,39,27,26} ; // 24,25 for SCA/SCL // physical pin numbers of each of the analog input pins
bool AIN_u[] = {true,true,true,true,true,true,true,true,true,false,false,true,false,false,false,false} ; // Array to select whether or not to collect data from the analog input - TH12 is the heater outlet temp
bool AIN_avg[] = {true,true,true,false,false,false,false,false,false,false,false,false,false,false,false,false}; // Array to select whether or not to include the thermistors in the oven temperarature average - note that the last 4 are always false, as they are not temperatures
// If the pin is in use, mark it to be read during the cure and cool states
const char *AIN_n[] = {"TH01","TH02","TH03","TH04","TH05","TH06","TH07","TH08","TH09","TH10","TH11","TH12","UA1","UA2","VS1","PIT1"} ;
// Names of all the analog input pins
bool SelfCheck = false ;

const int mapTherm[2][102] = {{993,985,975,962,948,930,911,888,862,834,803,770,734,697,658,619,580,541,503,466,430,396,364,334,306,280,256,234,214,195,178,163,149,136,125,115,105,97,89,82,75,70,64,59,55,51,47,44,41,38,36},{0,5,10,15,20,25,30,35,40,45,50,55,60,65,70,75,80,85,90,95,100,105,110,115,120,125,130,135,140,145,150,155,160,165,170,175,180,185,190,195,200,205,210,215,220,225,230,235,240,245,250}} ;
                              // 10k Thermistor Divider (Old board rev) {{786,736,682,626,568,512,457,405,356,312,273,238,207,180,156,136,118,103,90,78,69,60,53,47,41,37,33,29,26,23,21,19,17,15,14,12,11,10,9,8,8,7,6,6,5,5,4,4,4,3,3},{0,5,10,15,20,25,30,35,40,45,50,55,60,65,70,75,80,85,90,95,100,105,110,115,120,125,130,135,140,145,150,155,160,165,170,175,180,185,190,195,200,205,210,215,220,225,230,235,240,245,250}};

int AOUT[] =  {29,28} ; // Analog Output Pin Numbers
const char *AOUT_n[] = {"UA3","UA4"} ; // Analog Output Pin Names

int SW_c = 5 ; // Number of Switches
int SW[] = {3,4,5,6,7} ; // Switch Pin Numbers
const char *SW_n[] = {"OUT","UPW","DWN","SLT","RUN"} ; // Switch Names

IntervalTimer control_HTR1_Timer ; // Timer to run the slow PWM function
IntervalTimer blinkLED ; // Timer to blink the LED

int DRV_c = 7 ; // Number of drive outputs
int DRV[] = {11,13,12,32,8,9,10}; // Input Relay, Blower, Heater, Auxiliary, and LED Enable Pins 
const char *DRV_n[] = {"IRO1","BLW1","HTR1","AUX1","LED1","LED2","LED3"}; // Drive Output Names

int state = 1 ; // Start in the startup state
const char *state_n[] = {"OFF","STARTUP","CURE","ERROR"} ; // State Names

int SEN_IL = 1 ;

int error[6] = {0,0,0,0,0,0} ; // Array to store error code indexes
int error_c = 6 ; // Length of the error array
char *error_n[] = {"","IL BRK","TH BRK","TH OVT","VAC ERR","PGM NOK","TH ERR"} ; // Array to hold the error strings IL BRK: Interlock Loop Break, TH BRK: Thermistor Break, TH OVT: Thermistor Overtemperature,  VAC ERR: Vacuum level less than critical point, PGM NOK: Program has invalid settings, TH ERR: One of the thermistors failed on oven startup. Let the oven cool down or turn off the selfcheck.
int error_count = 0 ; // Running tally of the errors
 
char clearline = "                    " ; // 20 spaces to clear the display

bool stateChange = false ; // Boolean to allow the oven to pass by the remaining states after a transition
bool ILOK = false ;     // Boolean to indicate the state of the interlock loop
bool PGMOK = false ;  // Boolean to indicate the validity of the parameters (all positive, nonzero, temp less than Temp_Max_Part)
bool CURE = false ; // Boolean to indicate that the oven is in the CURE state
bool ERR = false ; // Bool to indicate the that the oven is in the ERR state
bool AUX = false ; // Bool to store the state of the auxiliary device
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

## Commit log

2023-02-23 Upload mechanical CAD
    [120VInlet.SLDPRT, 120VOutlet.SLDPRT, 2AMLSX.SLDPRT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]
2023-02-23 Added electrical schematics
    [EDI2CAP.CFG, Kycon_-_KLDX-0202-A.step, Mains.kicad_sch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]
2023-03-03 Added I2C Wire2 library
2023-03-04 Updated the panel schematic, added new files
    [Ovendata.xlsx, Thermistors.xlsx]
2023-03-04 Updated CuringOvenWiring with wire labels
2023-03-05 Updated electrical schematic with Shirleys feedback
2023-03-25 Updated wiring schematic with inspectors feedback
2023-05-16 Moved schematics to google drive
    [120VInlet.SLDPRT, 120VOutlet.SLDPRT, 2AMLSX.SLDPRT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]

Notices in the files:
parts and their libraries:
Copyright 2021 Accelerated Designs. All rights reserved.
